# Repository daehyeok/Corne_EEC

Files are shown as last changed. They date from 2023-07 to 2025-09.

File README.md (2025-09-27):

# Corne EEC (Corne Extended Electrostatic Capacitive)

A Corne-based electrostatic capacitive (EC) keyboard featuring a number row and one additional thumb key.

> [!WARNING]
> I am not an electrical engineer. PCB design may not be optimized and could contain bugs. Use this project at your own risk.

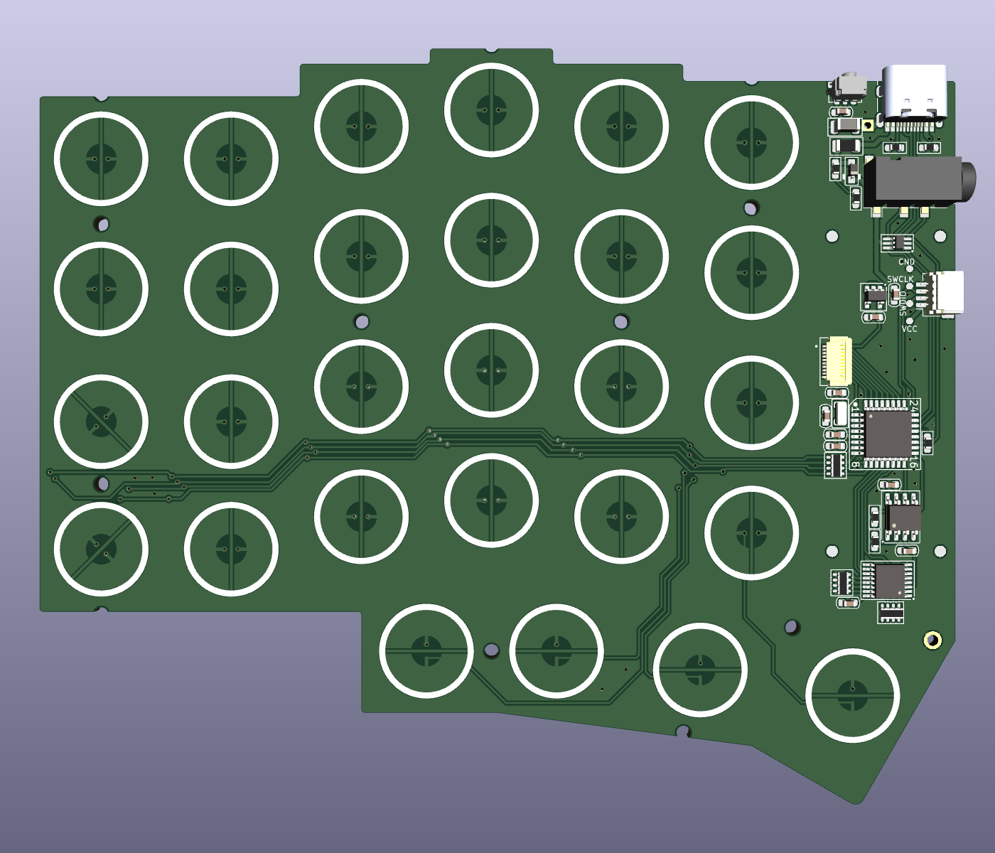
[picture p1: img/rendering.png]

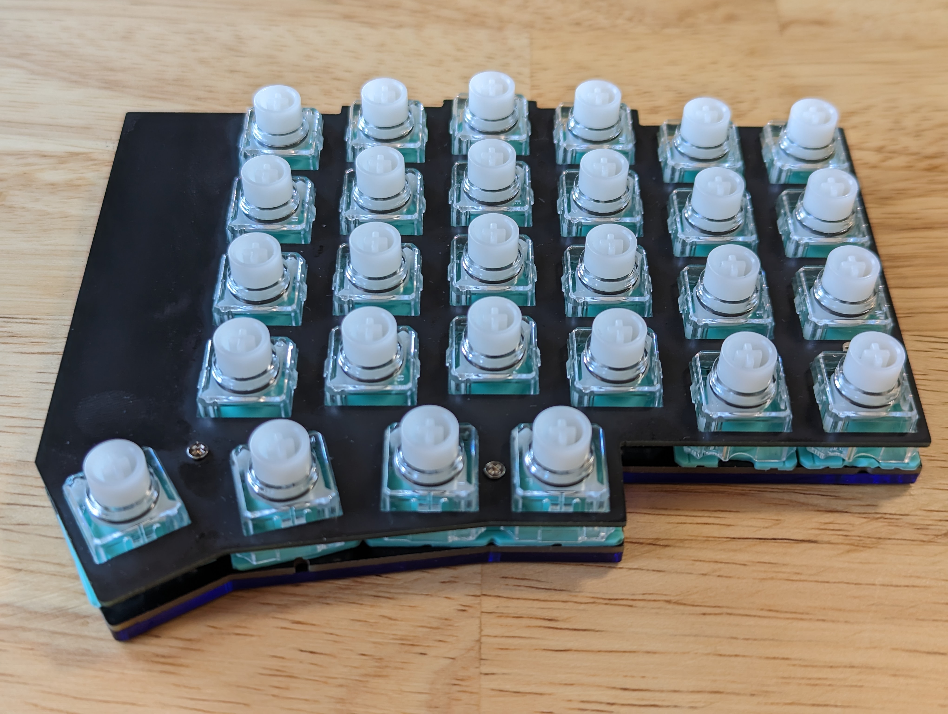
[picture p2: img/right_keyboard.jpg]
keyboard_img


## Features
* Corne-like design with a number row and 4 thumb keys, totaling 28 keys per half.
* Onboard STM32G431KBT6 MCU and USB-C with ESD protection.
* No through-hole components.
* ~~Extra PCB connectivity via a 1x06 FFC connector~~ **Rev2's FFC connector located upside down.**

## Firmware

The Rust-based firmware is hosted in a separate repository: [daehyeok/corne-eec-rs](https://github.com/daehyeok/corne-eec-rs).

## Credit

# Credit & Reference.

* [tomsmalley/custom-topre-guide](https://github.com/tomsmalley/custom-topre-guide): An invaluable resource for understanding custom Topre-style keyboards.
* [Cipulot](https://github.com/Cipulot)'s multiple PCB and firmware projects: A great source of inspiration for keyboard hardware and firmware development.
*  This project is forked from [Cipulot/CorneECRevival](https://github.com/Cipulot/CorneECRevival).

## Copyright

This project is released under the MIT License. Refer to the `LICENCE.md` file for details.

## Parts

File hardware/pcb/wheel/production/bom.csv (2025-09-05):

Designator | Footprint | Quantity | Value | LCSC Part #
H3_3, H3_2, H3, H4_3, H4_2, H4, H5_3, H5_2, H5, H6_3, H6_2, H6 | SMT-SO-M1.6-with-ring | 12 | ~
J4_3, J4_2, J4 | CONN6x1_FH34SRJ-6S-0.5SH50_HIR | 3 | HRS_FH34SRJ-06S-0.5SH(50)
R1_3, R1_2, R1, R2_3, R2_2, R2, R3_3, R3_2, R3 | 0603 | 9 | 10k
R4_3, R4_2, R4, R5_3, R5_2, R5, R6_3, R6_2, R6, R7_3, R7_2, R7, R8_3, R8_2, R8, R9_3, R9_2, R9 | 0603 | 18 | 0
SW1_3, SW1_2, SW1, SW2_3, SW2_2, SW2 | EVQWGD001 | 6 | RotaryEncoder_Switch

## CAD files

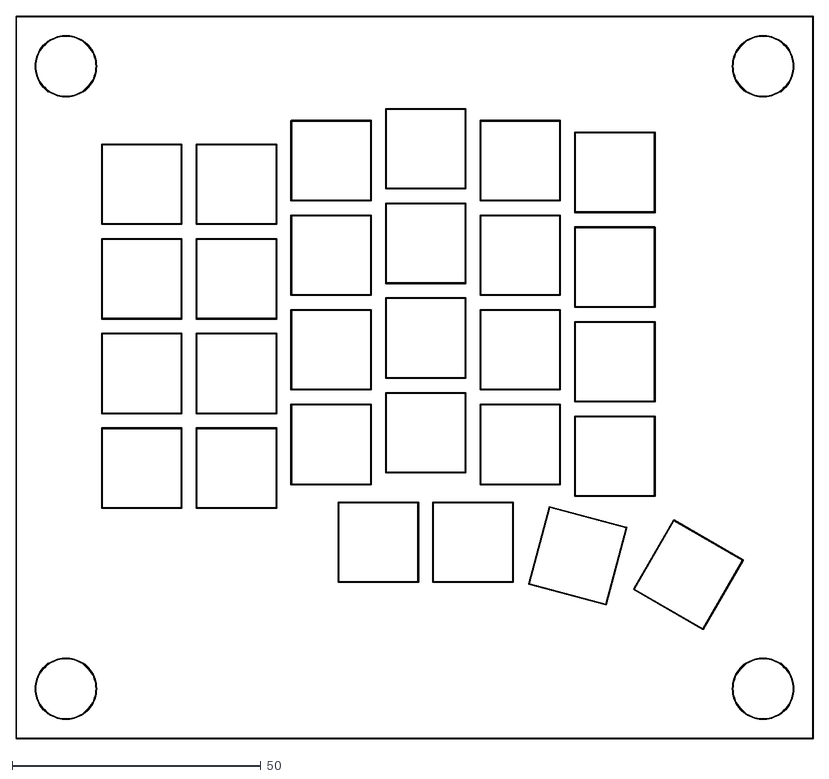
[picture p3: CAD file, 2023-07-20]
production_files/assembly_stand.dxf
160.1 x 145.1

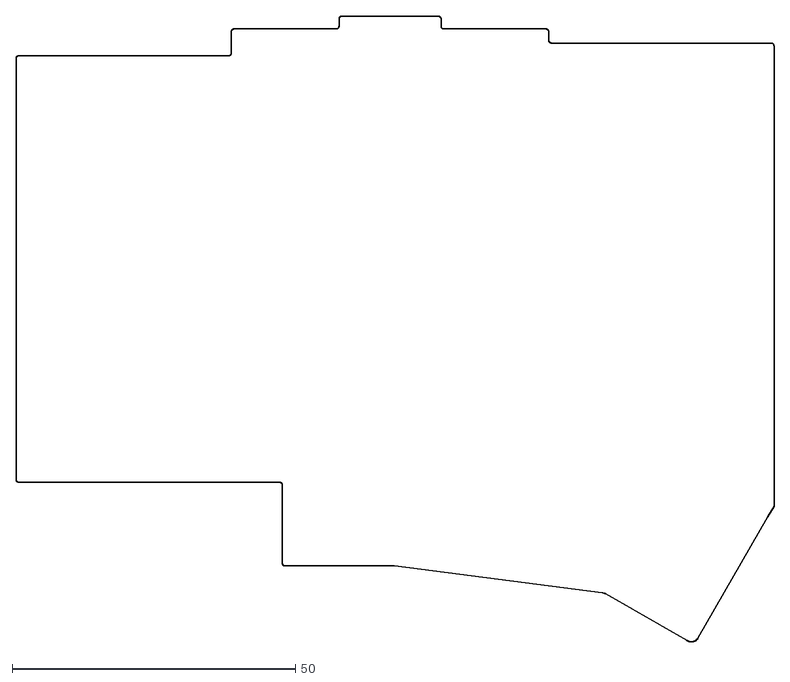
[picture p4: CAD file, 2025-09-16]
hardware/case/kicad/case-Edge_Cuts.dxf
133.8 x 110.4

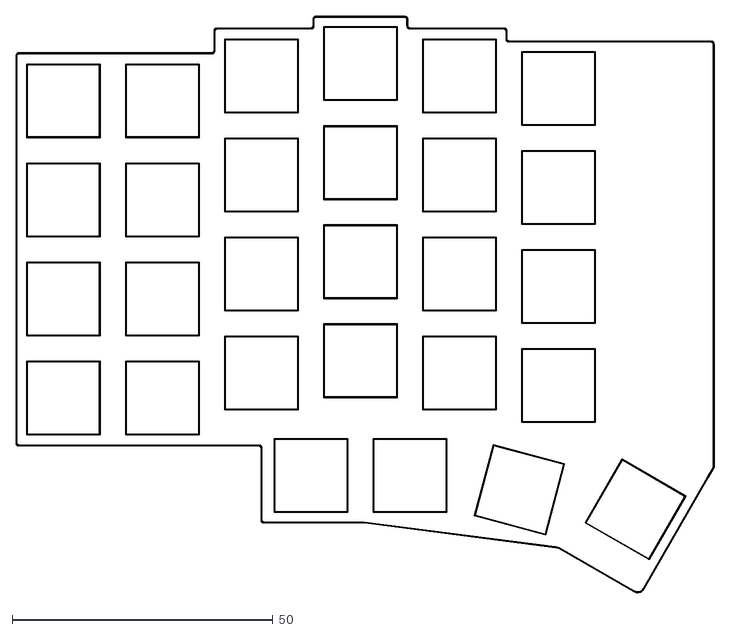
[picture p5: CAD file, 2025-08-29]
hardware/plain_plate/edge/plain_plate-Edge_Cuts.dxf
133.9 x 110.6

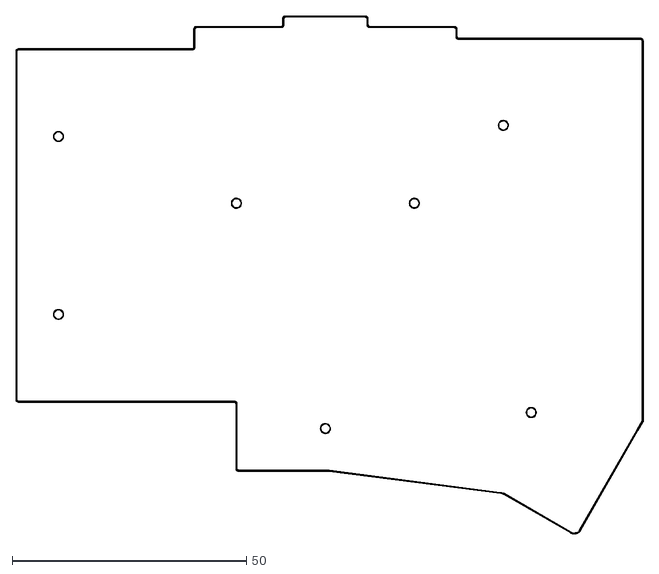
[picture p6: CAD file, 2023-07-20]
production_files/plain_plate.dxf
133.9 x 110.6

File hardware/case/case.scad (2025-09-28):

include <BOSL2/std.scad>;
$fn=64;

margin = 5;

//TODO - height
bottom_thickness = 1.5;
bottom_space = 1.5;

pcb_thickness = 1.6;
pcb_top_height = pcb_thickness;

plate_thickness = 1.2;
plate_bottom_height = pcb_top_height + 5;

standoff_height = 5;
wall_height = pcb_thickness + standoff_height + plate_thickness;

debug_jst_post= [121.773, 20.355];

usb_center_height = 3.26/2;
usb_pos = [118.05,  11.375];
//TODO fix value
usb_cutout_height = 6.5;
usb_cutout_width = 11.6;
usb_port_entry_width=11;


trrs_dia = 5.6;
trrs_radius = trrs_dia /2 ;
//x_pos == pcb_edge
trrs_pos = [124.75, -4.025, pcb_top_height +  trrs_radius];
//TODO fix value
trrs_cutout_dia = 7.5;

reset_center = 3.2/2;
reset_center_height = pcb_top_height + reset_center;
//y_pos == pcb_edge
reset_sw_pos = [108.65, 11.375, reset_center_height];
reset_dia = 2;
reset_cut_dia = 4;

//mount screw positions
m2_mount_pos = [ [38, -23.75],
                 [76, -23.75],
                 [57, -71.875],
                 ];

plate_mount_pos = [ [0, -9.5],
                    [0, -47.5],
                    [95, -7.125],
                    [100.9654, -68.4478],
                    ];

m2_screw_hole_dia = 2.05;



module pcb_outline_dxf(){
  import("./kicad/case-Edge_Cuts.dxf");
};

module pcb_cut_outline(){
  minkowski()
    {
      pcb_outline_dxf();
      circle(r=0.01);
    };
};


module case_outline(){
  minkowski()
    {
      pcb_outline_dxf();
      circle(r=margin);
    };
}

module bottom(){
  down(bottom_thickness)
    linear_extrude(bottom_thickness)
    pcb_cut_outline();
}

module wall(){
  down(bottom_thickness)
    linear_extrude(wall_height+bottom_thickness)
    difference(){
    case_outline();
    pcb_cut_outline();
  }
}

module core(){  
  union(){
    bottom();
    wall();
  }
}

module mount_cutout(){
  head_hole_dia = 4.5;
  head_hole_depth = 1;

  color("green")
    union(){
    for (pos = m2_mount_pos){
      move( concat(pos))
        down(bottom_thickness + 2)
        zrot(90)
        cylinder(d=m2_screw_hole_dia, h=10);
    }};
}

module plate_mount_cutout(){
  head_hole_dia = 4.5;
  head_hole_depth = 1;

  color("green")
    union(){
    for (pos = plate_mount_pos){
      move( concat(pos))
        down(head_hole_depth)
        zrot(-90)
        cylinder(d=head_hole_dia, h=head_hole_depth);
    }};
}


module usb_cutout_shape(){
  usb_extrude = 2;
  color("green")
    union(){
    up(pcb_thickness+0.5)
      left(usb_cutout_width/2)
      cube([usb_cutout_width, usb_extrude, 20]);
    up(usb_center_height + pcb_thickness)
      cuboid([usb_cutout_width, 20, usb_cutout_height], rounding=0.5);
  }
}
//TODO recheck
module usb_cut_out(){
  move(usb_pos)
    usb_cutout_shape();
}

//TODO
module trrs_cut_out(){
  move(trrs_pos)
    color("green")
    union(){
    cube([20, trrs_cutout_dia, 10], center=true);
  }
}

module reset_cut_out(){

  large_hole_dia =reset_cut_dia + 2;
  upside_entry_width=1.8;
  y_cut = 10;
  move(reset_sw_pos)
    color("green")
    union(){
    up(y_cut/2 - large_hole_dia/2)
      back(upside_entry_width/2)
      cube([large_hole_dia, upside_entry_width, y_cut], center = true);
    xrot(-90)
      union(){
      cylinder(d=reset_cut_dia, h = 10);
    }
  }
}

module case(){
  difference(){
    union(){
      core();
    }
    usb_cut_out();
    trrs_cut_out();
    reset_cut_out();
    mount_cutout();
    plate_mount_cutout();
  }
}

render(){
  case();
  usb_cutout_shape();
}

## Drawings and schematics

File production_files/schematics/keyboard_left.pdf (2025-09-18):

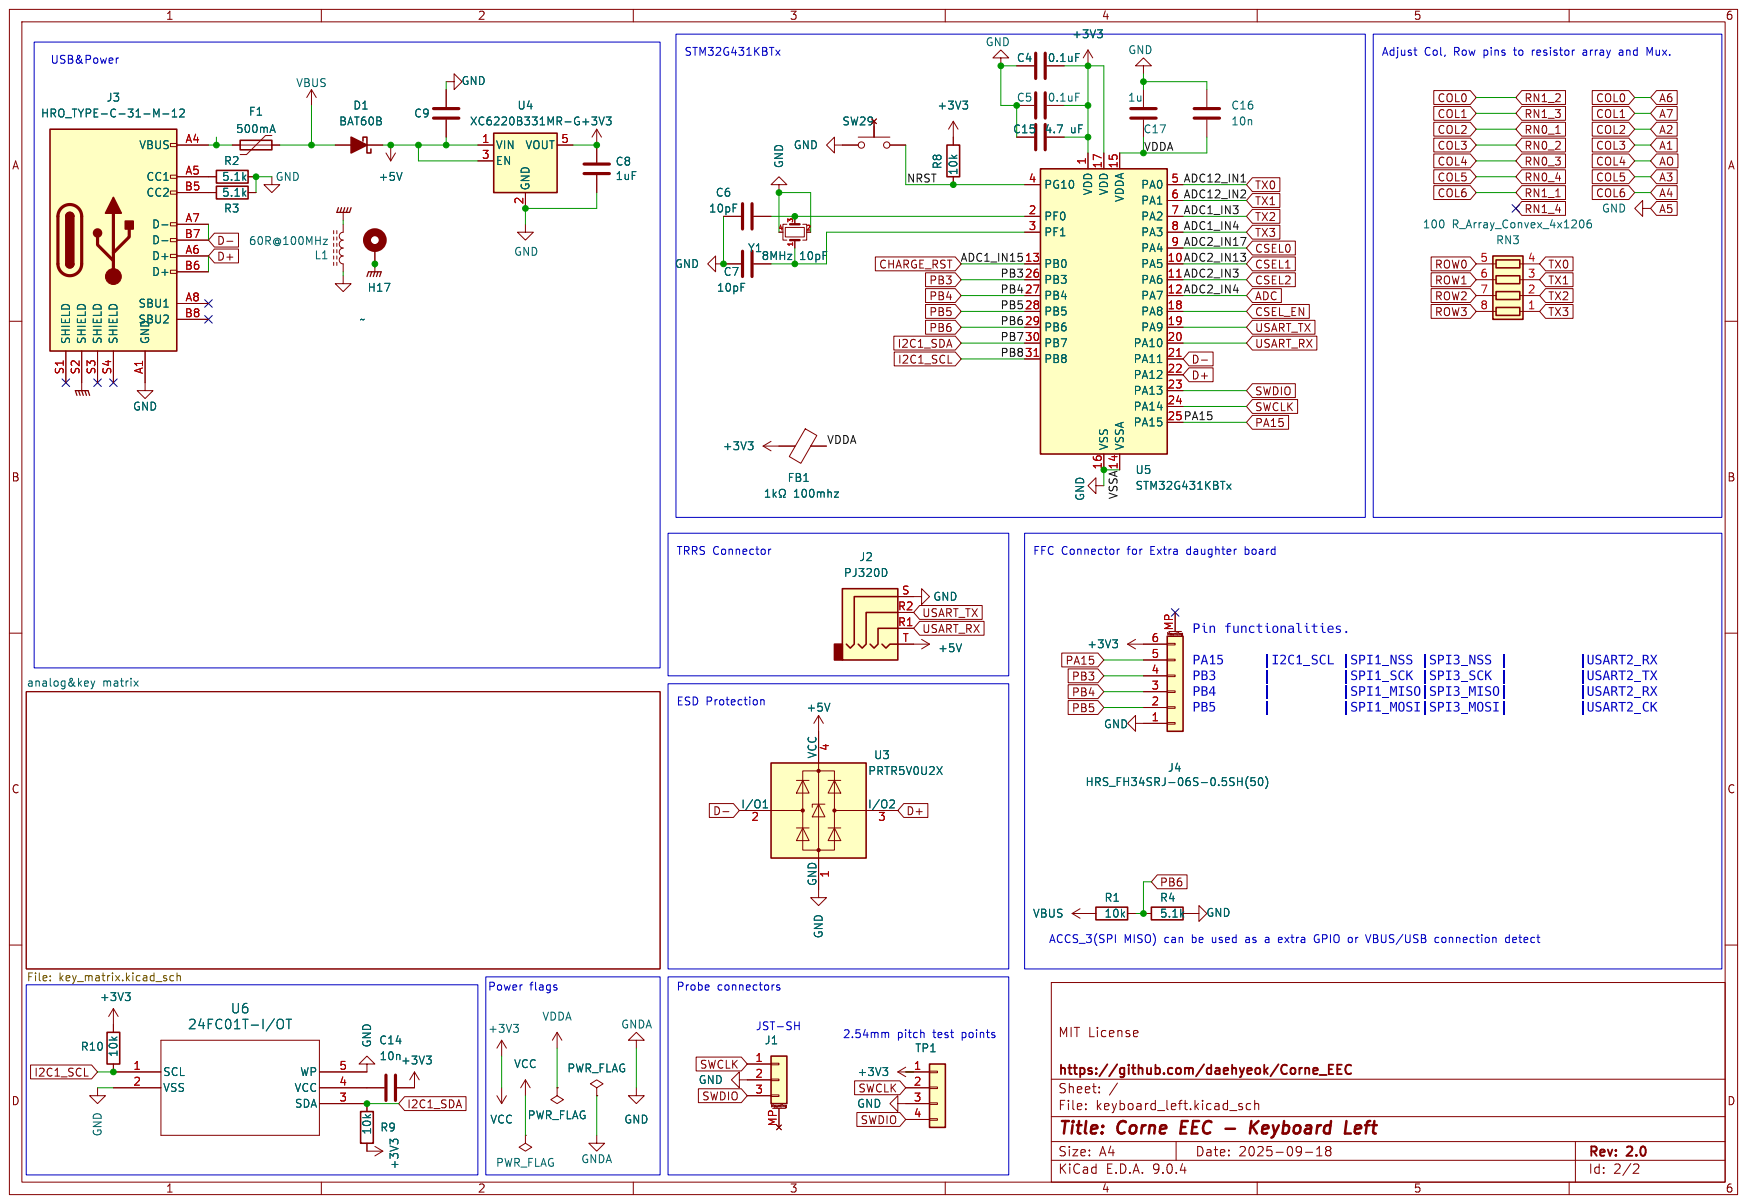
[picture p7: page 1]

https://github.com/daehyeok/Corne_EEC
Sheet: /
File: keyboard_left.kicad_sch

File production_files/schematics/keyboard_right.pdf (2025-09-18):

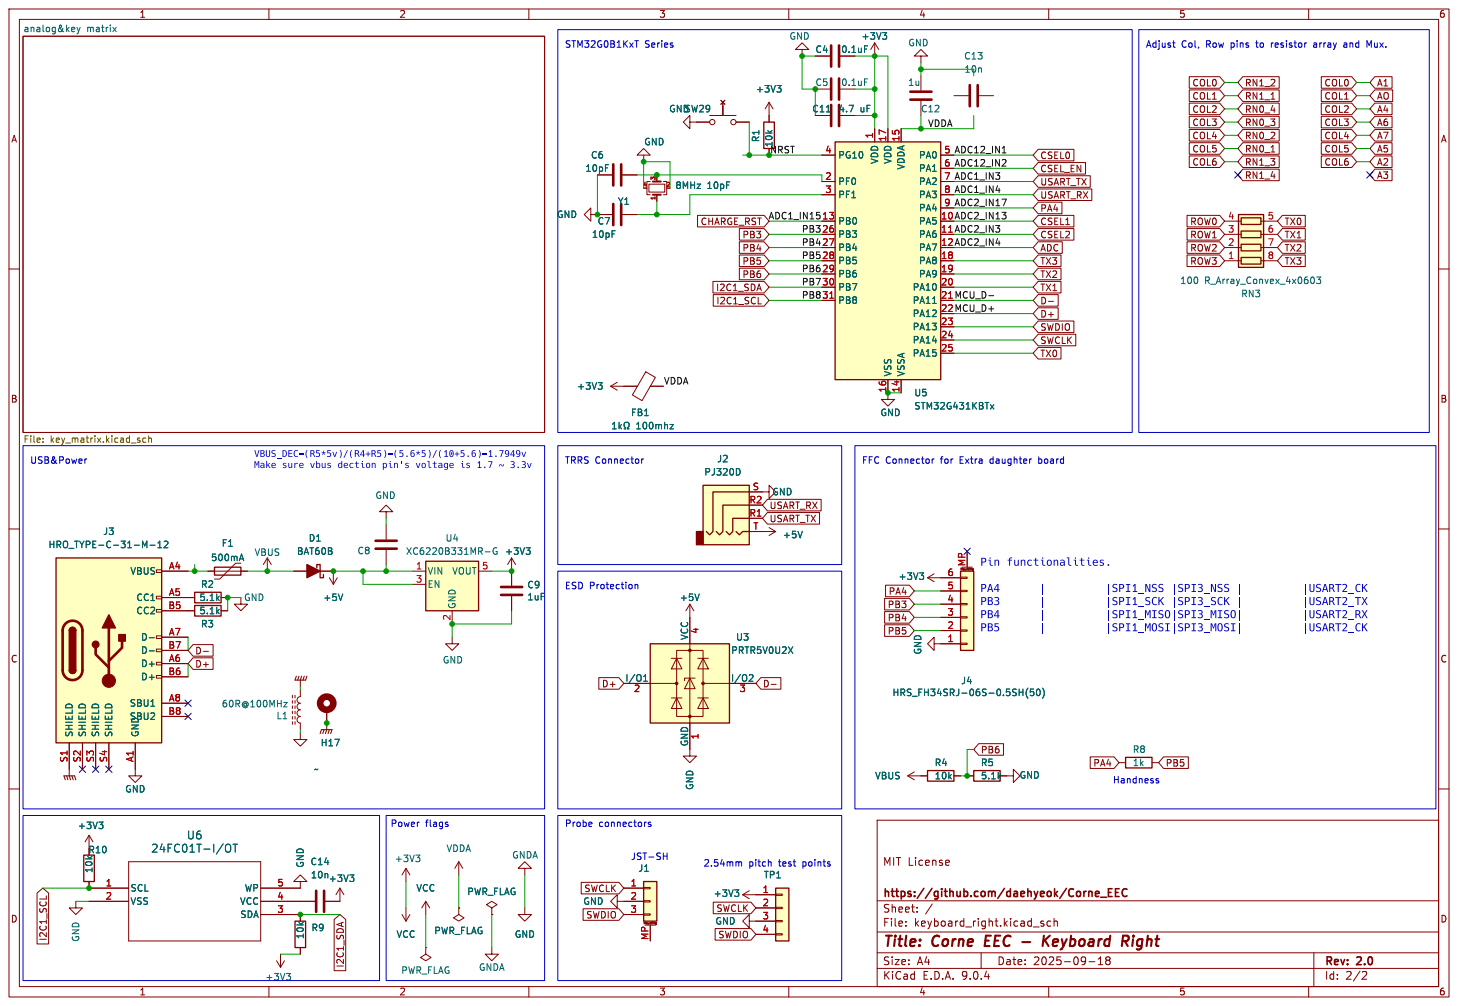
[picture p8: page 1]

1 VDD 17 VSS 16 VDDA 15 VSSA 14 PA0 5 PA1 6 PA2 7 PA3 8 PA4 9 PA5 10 PA6 11 PA7 12 PA8 18 PA9 19 PA10 20 PA11 21 PA12 22 PA13 23 PA14 24 PA15 25 U5STM32G431KBTx +3V3
1uGND

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

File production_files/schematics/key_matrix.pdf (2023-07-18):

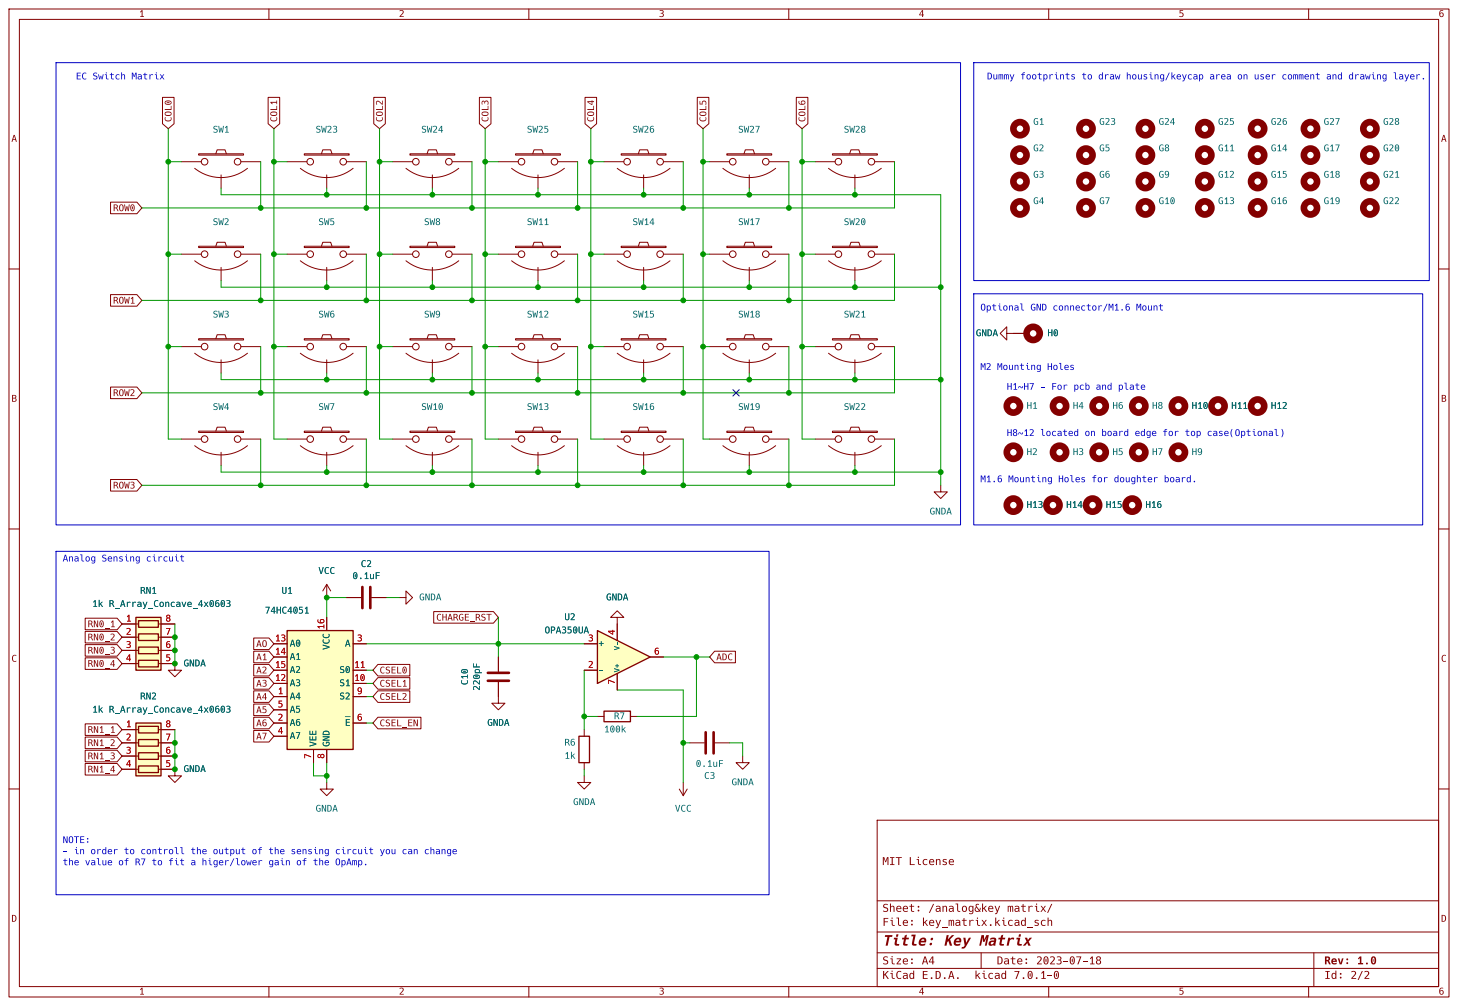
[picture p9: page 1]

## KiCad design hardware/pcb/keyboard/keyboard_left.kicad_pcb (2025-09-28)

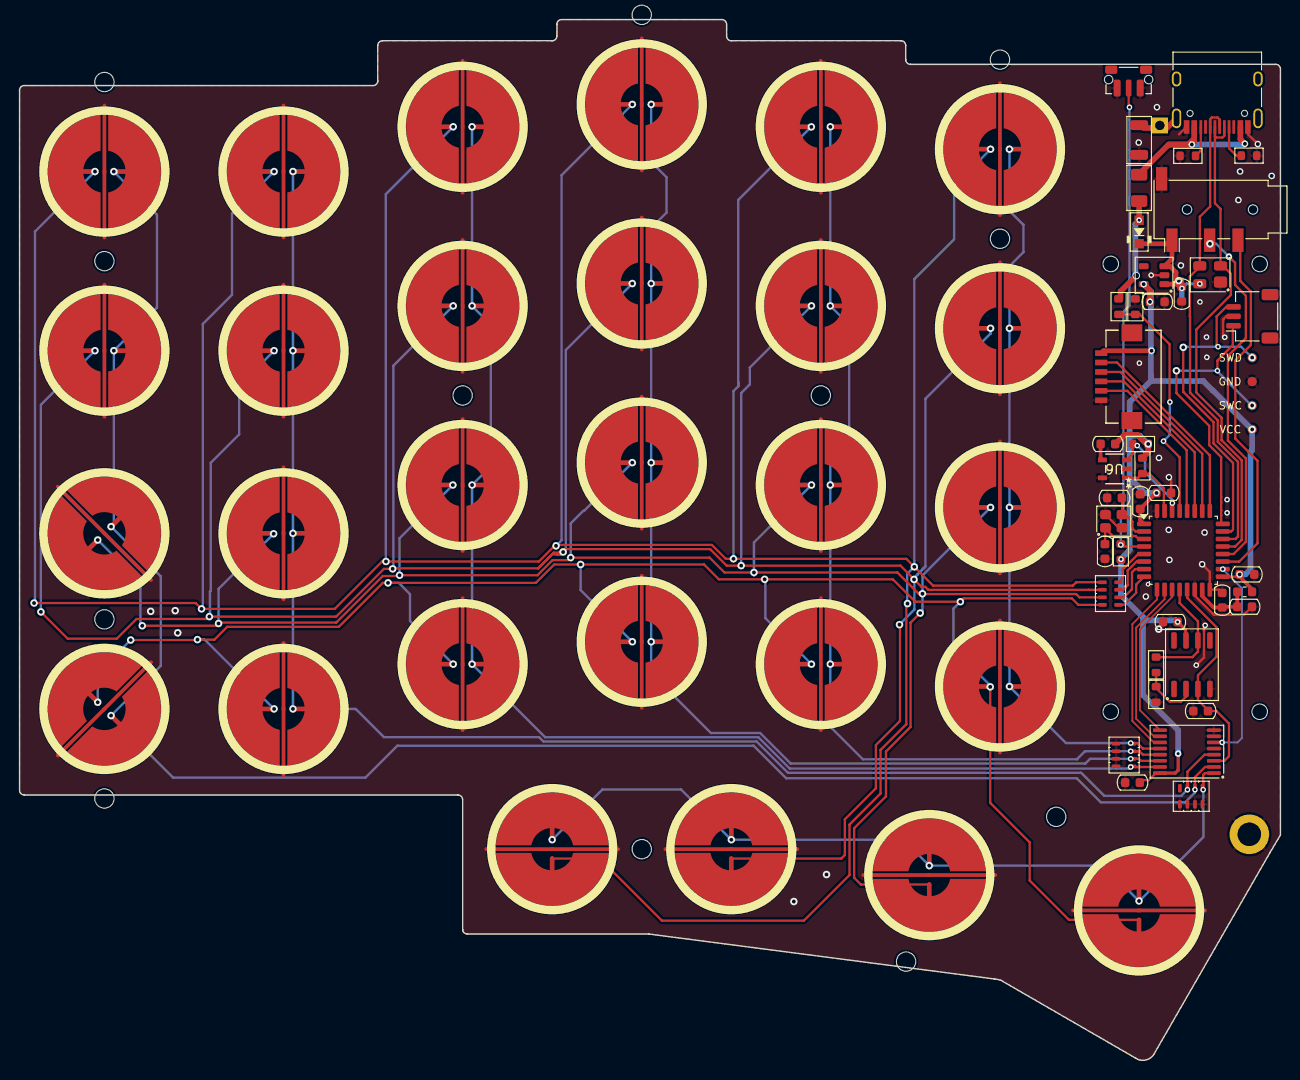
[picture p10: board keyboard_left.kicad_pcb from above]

Board: 2 copper layers, 133.8 x 110.4 mm, 116 parts (1 on the bottom side), 48 nets.

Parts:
C2, C3, C4, C5: 0.1uF; C_0603_1608Metric
C6, C7: 10pF; C_0603_1608Metric
C8, C9: 1uF; C_0603_1608Metric
C10: 220pF; C_0603_1608Metric
C14, C16: 10n; C_0603_1608Metric
C15: 4.7 uF; C_0603_1608Metric
C17: 1u; C_0603_1608Metric
D1: 1N5819; D_SOD-323_HandSoldering
F1: 500mA; Fuse_1206_3216Metric
FB1: 1kΩ 100mhz; L_0603_1608Metric
G1, G2, G3, G4, G5, G6, G7, G8, G9, G10, G11, G12, G13, G14, G15, G16, G17, G18, G19, G20, G21, G23, G24, G25, G26, G27, G28: ecs_housing_graphic
G22: ecs_housing_graphic_1.5U
H0: SMT-SO-M1.6-with-ring
H1, H2, H3, H4, H5, H6, H7, H8, H9, H10, H11, H12: MountingHole_2.05mm
H13, H14, H15, H16: SMT-SO-M1.6-screwhole_only
H17: PinHeader_1x01
J1: SM03B-SRSS-TB; JST_SH_SM03B-SRSS-TB_1x03-1MP_P1.00mm_Horizontal
J2: PJ320D; Jack_3.5mm_PJ320D_Horizontal
J3: HRO_TYPE-C-31-M-12; USB_C_Receptacle_HRO_TYPE-C-31-M-12
J4: HRS_FH34SRJ-06S-0.5SH(50); CONN6x1_FH12S-6S-1SH55
L1: 60R@100MHz; L_1206_3216Metric
R1, R8, R9, R10: 10k; R_0603_1608Metric
R2, R3, R4: 5.1k; R_0603_1608Metric
R6: 1k; R_0603_1608Metric
R7: 100k; R_0603_1608Metric
RN1, RN2: 100k R_Array_Concave_4x0603; R_Array_Concave_4x0603
RN3: 100 R_Array_Convex_4x1206; R_Array_Concave_4x0603
SW1, SW2, SW3, SW4, SW5, SW6, SW7, SW8, SW9, SW10, SW11, SW12, SW13, SW14, SW15, SW16, SW17, SW18, SW19, SW20, SW21, SW22, SW23, SW24, SW25, SW26, SW27, SW28: ecs_pad_no_ring
SW29: PTS845; SW_Push_1P1T-MP_NO_Horizontal_Alps_SKRTLAE010
TP1: PinHeader_1x04_P2.54mm_test_pad
U1: 74HC4051; TSSOP-16_4.4x5mm_P0.65mm
U2: OPA350UA; SO-8_3.9x4.9mm_P1.27mm
U3: PRTR5V0U2X; SOT-143
U4: XC6220B331MR-G; SOT-23-5
U5: STM32G431KBTx; LQFP-32_7x7mm_P0.8mm
U6: 24FC01T-I/OT; SOT-23-5_2P9X1P6_MCH
Y1: 8MHz 10pF; Crystal_SMD_2520-4Pin_2.5x2.0mm

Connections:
+3V3: C2.2, C3.2, C4.1, C5.1, C8.1, C14.1, C15.1, FB1.2, J4.6, R8.2, R9.2, R10.1, TP1.1, U1.16 (VCC), U2.7 (V+), U4.5 (VOUT), U5.1 (VDD), U5.17 (VDD)
+5V: C9.1, D1.1 (K), J2.T, U3.4 (VCC), U4.1 (VIN), U4.3 (EN)
/NRST: R8.1, SW29.2, U5.4 (PG10)
A1: RN1.2 (R2.1), SW11.1, SW12.1, SW13.1, SW25.1, U1.14 (A1)
A2: RN1.1 (R1.1), SW8.1, SW9.1, SW10.1, SW24.1, U1.15 (A2)
A3: RN1.4 (R4.1), SW17.1, SW18.1, SW19.1, SW27.1, U1.12 (A3)
A4: RN2.1 (R1.1), SW20.1, SW21.1, SW22.1, SW28.1, U1.1 (A4)
A5: C2.1, C3.1, C4.2, C5.2, C6.1, C7.1, C8.2, C9.2, C10.2, C15.2, C16.2, C17.2, H0.1, J1.2, J2.S, J3.A1 (GND), J3.A12 (GND), J3.B1 (GND), J3.B12 (GND), J4.1, L1.1, R2.2, R3.2, R4.1, R6.2, RN1.5 (R4.2), RN1.6 (R3.2), RN1.7 (R2.2), RN1.8 (R1.2), RN2.5 (R4.2), RN2.6 (R3.2), RN2.7 (R2.2), RN2.8 (R1.2), SW1.3 (SG), SW2.3 (SG), SW3.3 (SG), SW4.3 (SG), SW5.3 (SG), SW6.3 (SG), SW7.3 (SG), SW8.3 (SG), SW9.3 (SG), SW10.3 (SG), SW11.3 (SG), SW12.3 (SG), SW13.3 (SG), SW14.3 (SG), SW15.3 (SG), SW16.3 (SG), SW17.3 (SG), SW18.3 (SG), SW19.3 (SG), SW20.3 (SG), SW21.3 (SG), SW22.3 (SG), SW23.3 (SG), SW24.3 (SG), SW25.3 (SG), SW26.3 (SG), SW27.3 (SG), SW28.3 (SG), SW29.1, TP1.3, U1.5 (A5), U1.7 (VEE), U1.8 (GND), U2.4 (V-), U3.1 (GND), U4.2 (GND), U5.14 (VSSA), U5.16 (VSS), U5.32 (VSS), U6.2 (VSS), U6.5 (WP), Y1.2, Y1.4
A6: RN2.2 (R2.1), SW1.1, SW2.1, SW3.1, SW4.1, U1.2 (A6)
A7: RN2.3 (R3.1), SW5.1, SW6.1, SW7.1, SW23.1, U1.4 (A7)
ADC: R7.1, U2.6, U5.12 (PA7)
AO: RN1.3 (R3.1), SW14.1, SW15.1, SW16.1, SW26.1, U1.13 (A0)
CHARGE_RST: C10.1, U1.3 (A), U2.3 (+), U5.13 (PB0)
CSEL0: U1.11 (S0), U5.9 (PA4)
CSEL1: U1.10 (S1), U5.10 (PA5)
CSEL2: U1.9 (S2), U5.11 (PA6)
CSEL_EN: U1.6 (~E), U5.18 (PA8)
D+: J3.A6 (D+), J3.B6 (D+), U3.3 (I/O2), U5.22 (PA12)
D-: J3.A7 (D-), J3.B7 (D-), U3.2 (I/O1), U5.21 (PA11)
GNDPWR: H17.1, J3.S2 (SHIELD), L1.2
I2C1_SCL: R10.2, U5.31 (PB8), U6.1 (SCL)
I2C1_SDA: R9.1, U5.30 (PB7), U6.3 (SDA)
unnamed: F1.2, J3.A4 (VBUS), J3.A9 (VBUS), J3.B4 (VBUS), J3.B9 (VBUS)
unnamed: J3.A5 (CC1), R2.1
unnamed: J3.B5 (CC2), R3.1
unnamed: R6.1, R7.2, U2.2 (-)
unnamed: C6.2, U5.2 (PF0), Y1.3
unnamed: C7.2, U5.3 (PF1), Y1.1
unnamed: C14.2, U6.4 (VCC)
PA15: J4.5, U5.25 (PA15)
PB3: J4.4, U5.26 (PB3)
PB4: J4.3, U5.27 (PB4)
PB5: J4.2, U5.28 (PB5)
PB6: R1.1, R4.2, U5.29 (PB6)
ROW0: RN3.5 (R4.2), SW1.2, SW23.2, SW24.2, SW25.2, SW26.2, SW27.2, SW28.2
ROW1: RN3.6 (R3.2), SW2.2, SW5.2, SW8.2, SW11.2, SW14.2, SW17.2, SW20.2
ROW2: RN3.7 (R2.2), SW3.2, SW6.2, SW9.2, SW12.2, SW15.2, SW18.2, SW21.2
ROW3: RN3.8 (R1.2), SW4.2, SW7.2, SW10.2, SW13.2, SW16.2, SW19.2, SW22.2
SWCLK: J1.1, TP1.2, U5.24 (PA14)
SWDIO: J1.3, TP1.4, U5.23 (PA13)
TX0: RN3.4 (R4.1), U5.5 (PA0)
TX1: RN3.3 (R3.1), U5.6 (PA1)
TX2: RN3.2 (R2.1), U5.7 (PA2)
TX3: RN3.1 (R1.1), U5.8 (PA3)
USART_RX: J2.R1, U5.20 (PA10)
USART_TX: J2.R2, U5.19 (PA9)
VBUS: D1.2 (A), F1.1, R1.2
VDDA: C16.1, C17.1, FB1.1, U5.15 (VDDA)

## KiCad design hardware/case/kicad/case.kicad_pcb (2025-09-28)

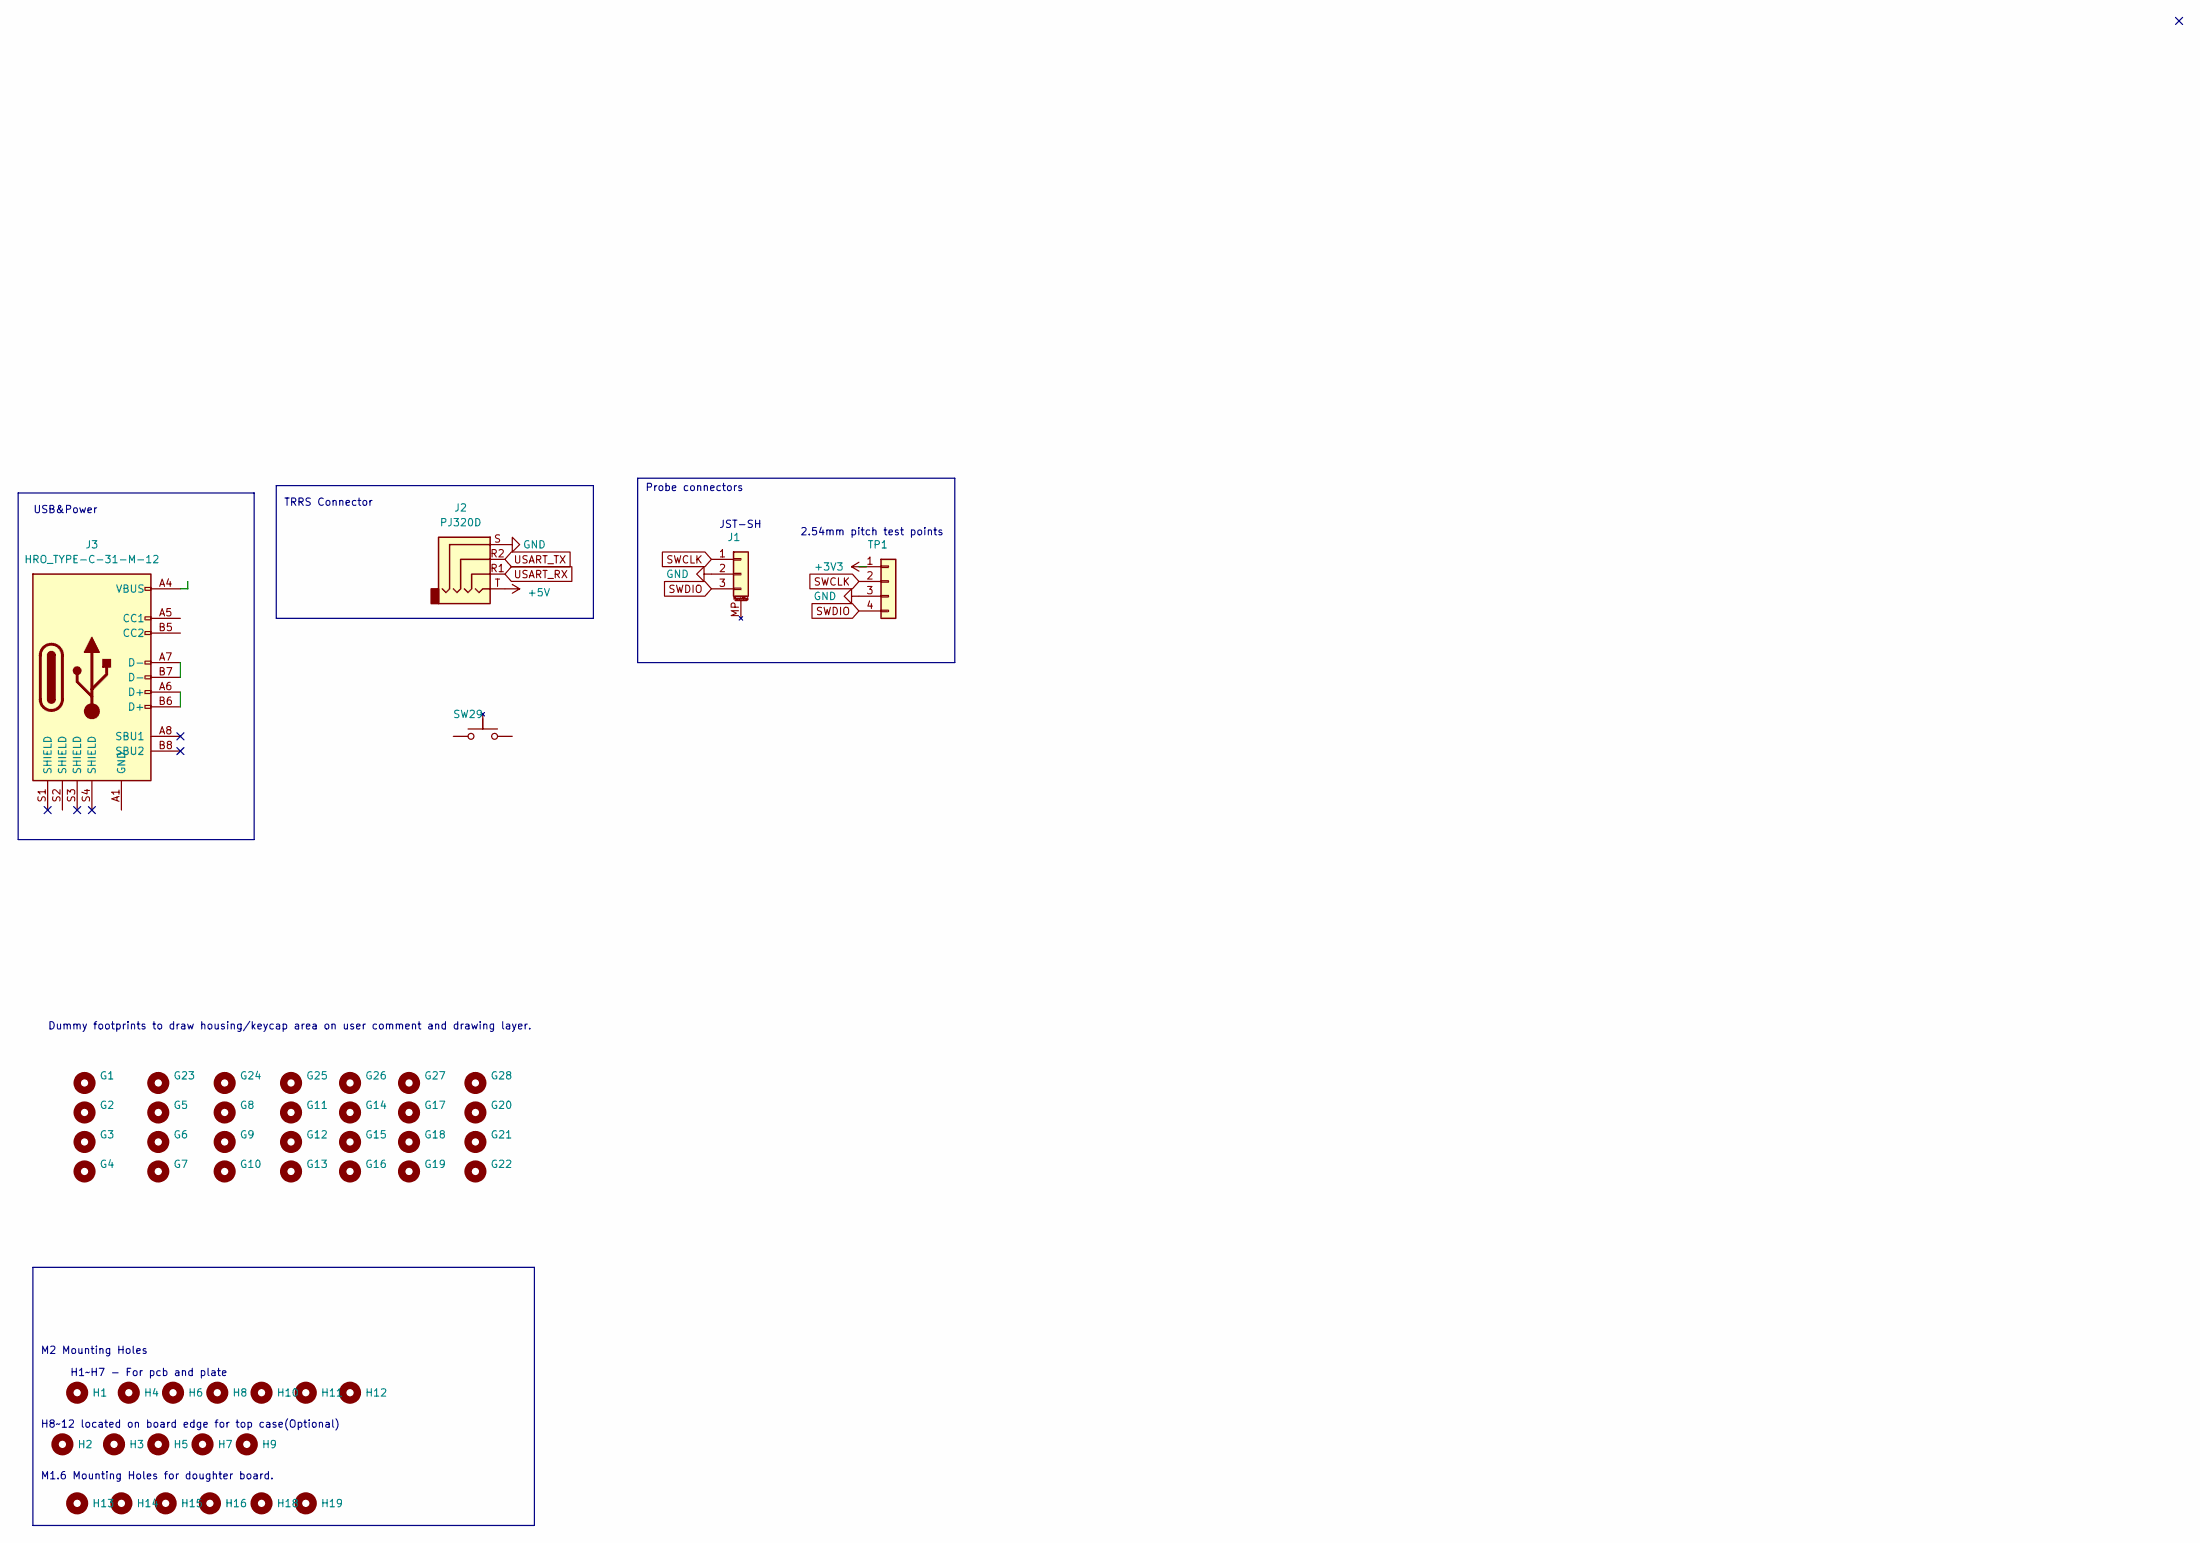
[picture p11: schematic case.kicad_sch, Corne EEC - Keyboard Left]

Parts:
G1, G2, G3, G4, G5, G6, G7, G8, G9, G10, G11, G12, G13, G14, G15, G16, G17, G18, G19, G20, G21, G23, G24, G25, G26, G27, G28: ecs_housing_graphic
G22: ecs_housing_graphic_1.5U
H1, H2, H3, H4, H5, H6, H7, H8, H9, H10, H11, H12: MountingHole_2.05mm
H13, H14, H15, H16, H18, H19: SMT-SO-M1.6-screwhole_only
J1: SM03B-SRSS-TB; JST_SH_SM03B-SRSS-TB_1x03-1MP_P1.00mm_Horizontal
J2: PJ320D; Jack_3.5mm_PJ320D_Horizontal
J3: HRO_TYPE-C-31-M-12; USB_C_Receptacle_HRO_TYPE-C-31-M-12
SW29: PTS845; SW_Push_1P1T-MP_NO_Horizontal_Alps_SKRTLAE010
TP1: PinHeader_1x04_P2.54mm_test_pad

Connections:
+3V3: TP1.1
+5V: J2.T
GND: J1.2, J2.S, TP1.3
unnamed: J3.A6 (D+), J3.B6 (D+)
unnamed: J3.A7 (D-), J3.B7 (D-)
unnamed: J3.A1 (GND), J3.A12 (GND), J3.B1 (GND), J3.B12 (GND)
unnamed: J3.A4 (VBUS), J3.A9 (VBUS), J3.B4 (VBUS), J3.B9 (VBUS)
SWCLK: J1.1, TP1.2
SWDIO: J1.3, TP1.4
USART_RX: J2.R1
USART_TX: J2.R2

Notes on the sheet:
Probe connectors
TRRS Connector
USB&Power
JST-SH
M2 Mounting Holes
M1.6 Mounting Holes for doughter board.
Dummy footprints to draw housing/keycap area on user comment and drawing layer.
H1~H7 - For pcb and plate
2.54mm pitch test points
H8~12 located on board edge for top case(Optional)

Board: 2 copper layers, 52 parts (1 on the bottom side), 7 nets, no tracks yet.

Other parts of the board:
H12#2: MountingHole_2.05mm

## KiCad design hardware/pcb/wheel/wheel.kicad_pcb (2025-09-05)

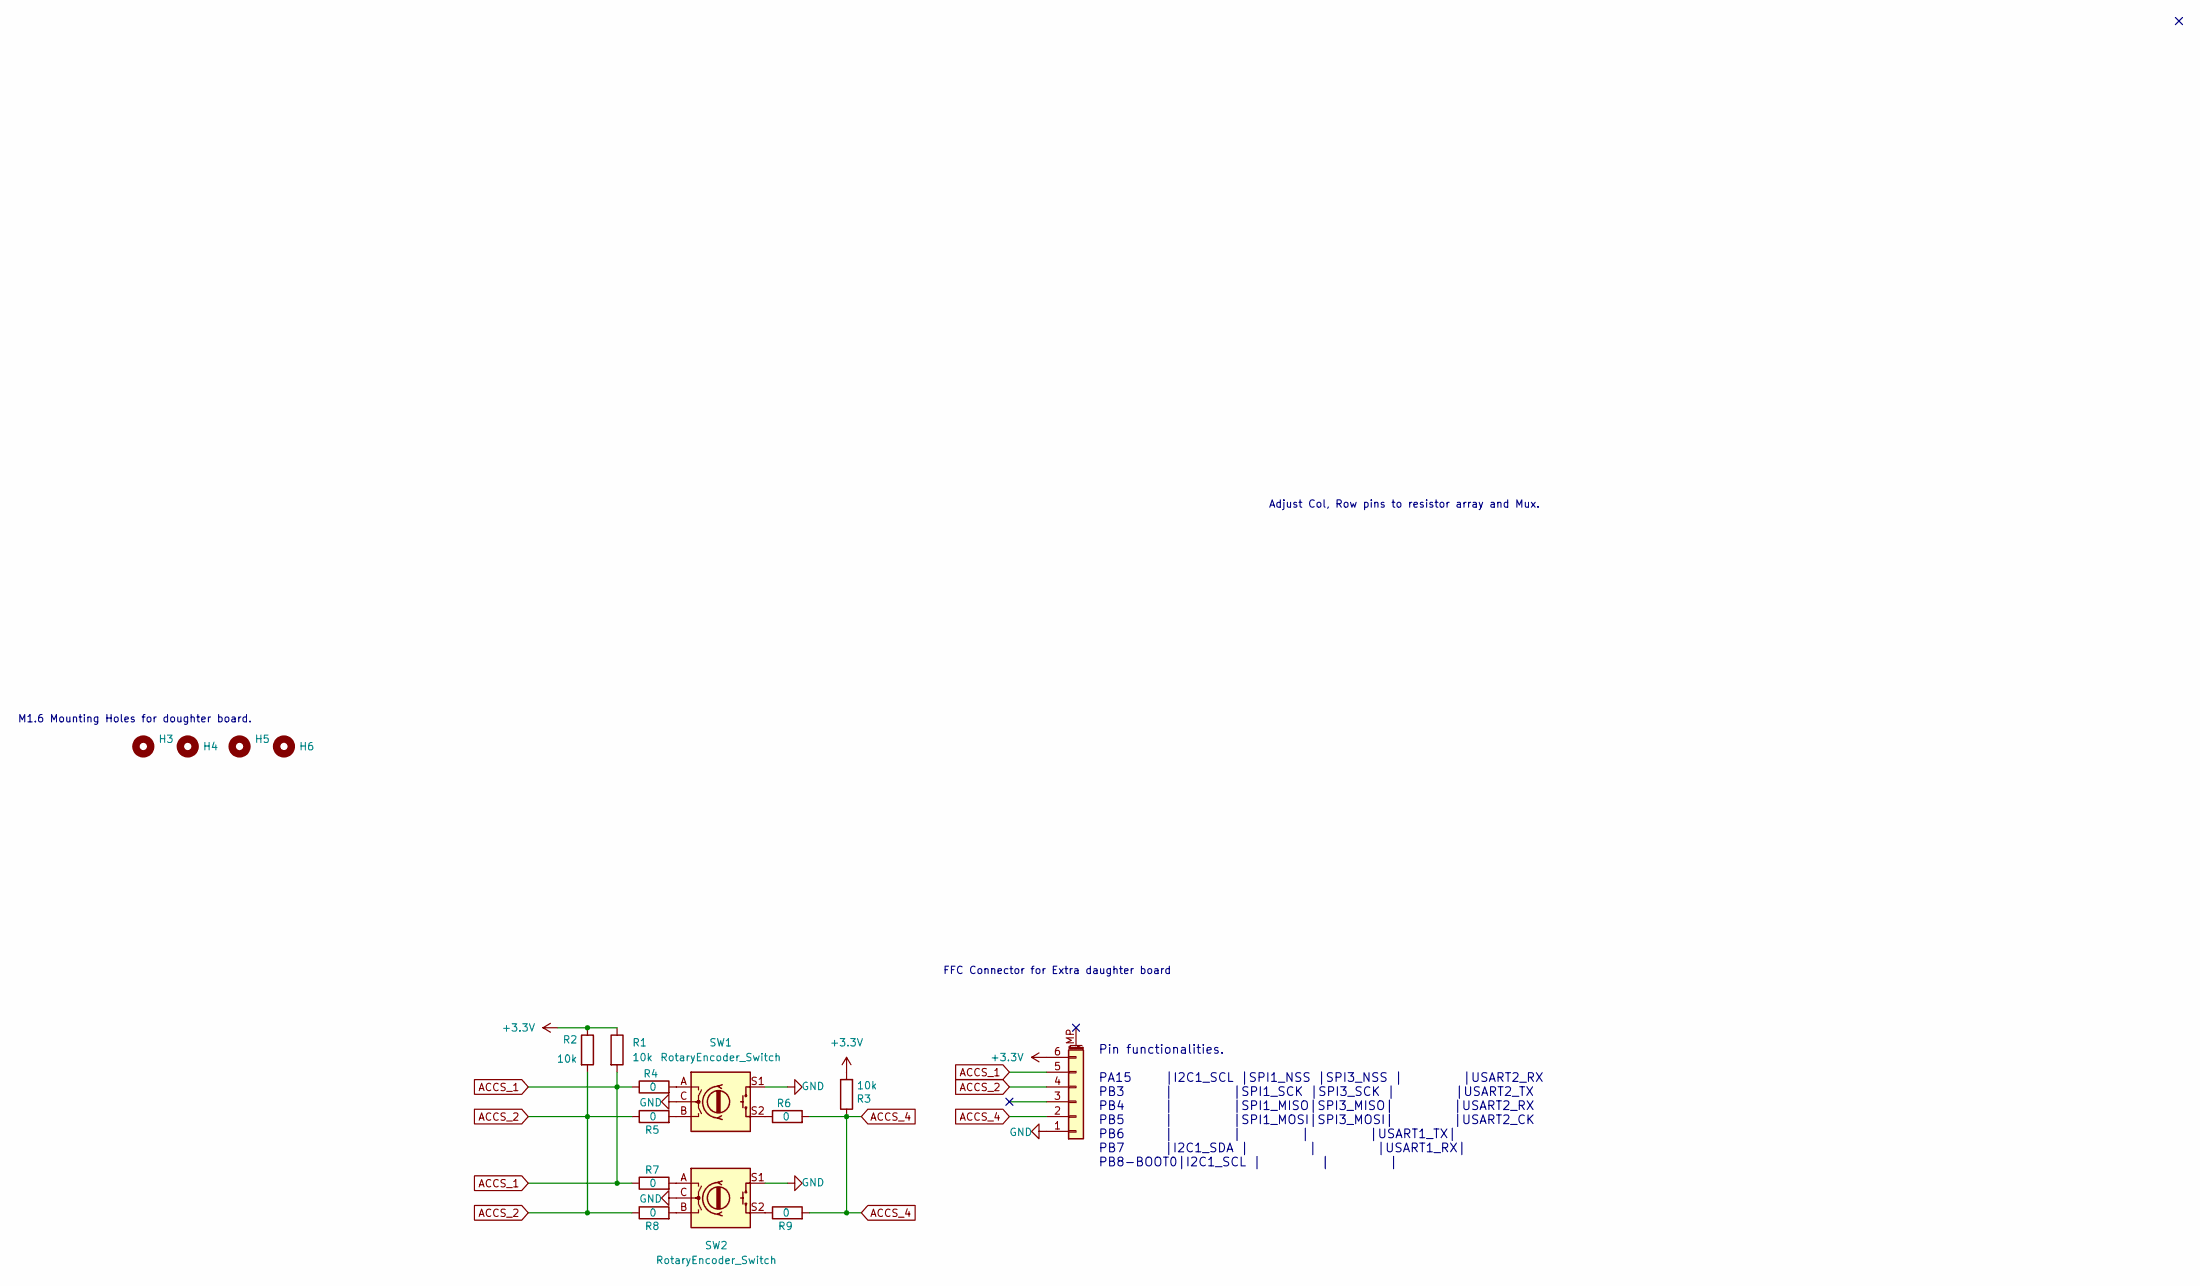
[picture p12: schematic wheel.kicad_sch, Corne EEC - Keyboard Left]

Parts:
H3, H4, H5, H6: SMT-SO-M1.6-screwhole_only
J4: HRS_FH34SRJ-06S-0.5SH(50); CONN6x1_FH34SRJ-6S-0.5SH50_HIR
R1, R2, R3: 10k; R_0603_1608Metric_Pad1.05x0.95mm_HandSolder
R4, R5, R6, R7, R8, R9: 0; R_0603_1608Metric_Pad1.05x0.95mm_HandSolder
SW1, SW2: RotaryEncoder_Switch; EVQWGD001

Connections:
+3.3V: J4.6, R1.1, R2.1, R3.2
ACCS_1: J4.5, R1.2, R4.1, R7.1
ACCS_2: J4.4, R2.2, R5.1, R8.1
ACCS_4: J4.2, R3.1, R6.2, R9.2
GND: J4.1, SW1.C, SW1.S1, SW2.C, SW2.S1
unnamed: R4.2, SW1.A
unnamed: R5.2, SW1.B
unnamed: R6.1, SW1.S2
unnamed: R7.2, SW2.A
unnamed: R8.2, SW2.B
unnamed: R9.1, SW2.S2

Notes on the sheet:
FFC Connector for Extra daughter board
Adjust Col, Row pins to resistor array and Mux.
M1.6 Mounting Holes for doughter board.
Pin functionalities. PA15 |I2C1_SCL |SPI1_NSS |SPI3_NSS | |USART2_RX PB3 | |SPI1_SCK |SPI3_SCK | |USART2_TX PB4 | |SPI1_MISO|SPI3_MISO| |USART2_RX PB5 | |SPI1_MOSI|SPI3_MOSI| |USART2_CK PB6 | | | |USART1_TX| PB7 |I2C1_SDA | | |USART1_RX| PB8-BOOT0|I2C1_SCL | | |

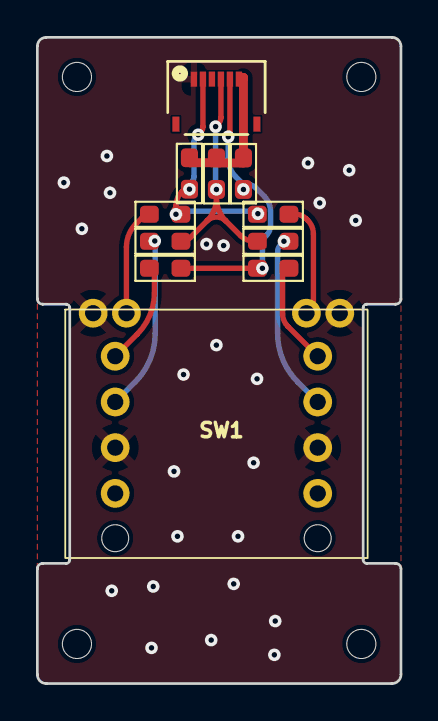
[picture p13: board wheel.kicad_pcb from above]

Board: 2 copper layers, 20.2 x 35.9 mm, 16 parts (1 on the bottom side), 11 nets.

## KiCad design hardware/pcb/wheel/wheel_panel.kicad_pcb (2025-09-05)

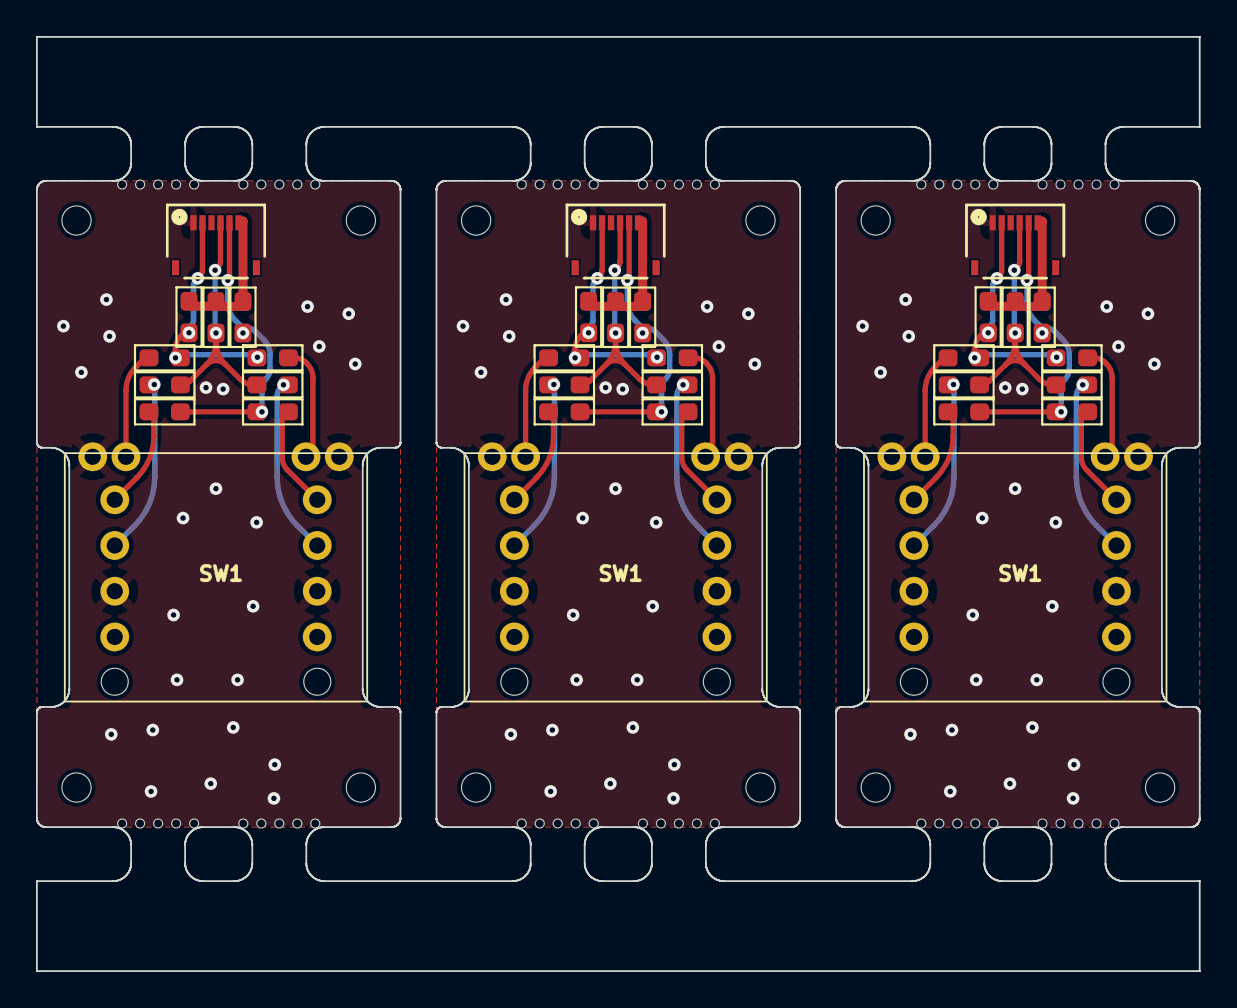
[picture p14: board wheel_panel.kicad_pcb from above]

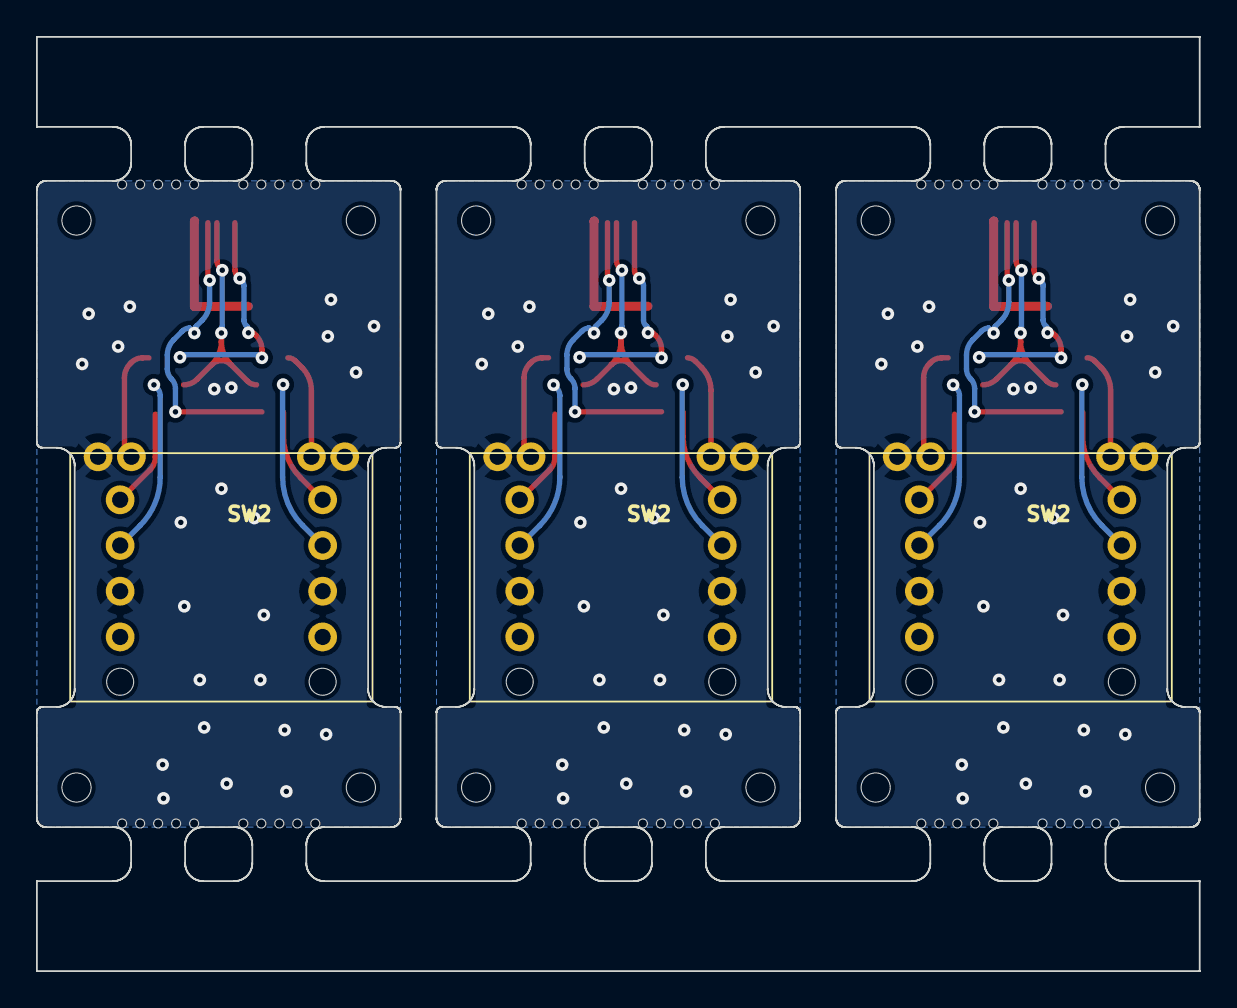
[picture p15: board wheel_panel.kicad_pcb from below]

Board: 2 copper layers, 64.6 x 51.9 mm, 108 parts (3 on the bottom side), 33 nets.

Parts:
H3, H3#2, H3#3, H4, H4#2, H4#3, H5, H5#2, H5#3, H6, H6#2, H6#3: SMT-SO-M1.6-with-ring
J4, J4#2, J4#3: HRS_FH34SRJ-06S-0.5SH(50); CONN6x1_FH34SRJ-6S-0.5SH50_HIR
KiKit_MB_1_1, KiKit_MB_1_2, KiKit_MB_1_3, KiKit_MB_1_4, KiKit_MB_1_5, KiKit_MB_2_1, KiKit_MB_2_2, KiKit_MB_2_3, KiKit_MB_2_4, KiKit_MB_2_5, KiKit_MB_3_1, KiKit_MB_3_2, KiKit_MB_3_3, KiKit_MB_3_4, KiKit_MB_3_5, KiKit_MB_4_1, KiKit_MB_4_2, KiKit_MB_4_3, KiKit_MB_4_4, KiKit_MB_4_5, KiKit_MB_5_1, KiKit_MB_5_2, KiKit_MB_5_3, KiKit_MB_5_4, KiKit_MB_5_5, KiKit_MB_6_1, KiKit_MB_6_2, KiKit_MB_6_3, KiKit_MB_6_4, KiKit_MB_6_5, KiKit_MB_7_1, KiKit_MB_7_2, KiKit_MB_7_3, KiKit_MB_7_4, KiKit_MB_7_5, KiKit_MB_8_1, KiKit_MB_8_2, KiKit_MB_8_3, KiKit_MB_8_4, KiKit_MB_8_5, KiKit_MB_9_1, KiKit_MB_9_2, KiKit_MB_9_3, KiKit_MB_9_4, KiKit_MB_9_5, KiKit_MB_10_1, KiKit_MB_10_2, KiKit_MB_10_3, KiKit_MB_10_4, KiKit_MB_10_5, KiKit_MB_11_1, KiKit_MB_11_2, KiKit_MB_11_3, KiKit_MB_11_4, KiKit_MB_11_5, KiKit_MB_12_1, KiKit_MB_12_2, KiKit_MB_12_3, KiKit_MB_12_4, KiKit_MB_12_5: NPTH
R1, R1#2, R1#3, R2, R2#2, R2#3, R3, R3#2, R3#3: 10k; R_0603_1608Metric_Pad1.05x0.95mm_HandSolder
R4, R4#2, R4#3, R5, R5#2, R5#3, R6, R6#2, R6#3, R7, R7#2, R7#3, R8, R8#2, R8#3, R9, R9#2, R9#3: 0; R_0603_1608Metric_Pad1.05x0.95mm_HandSolder
SW1, SW1#2, SW1#3, SW2, SW2#2, SW2#3: RotaryEncoder_Switch; EVQWGD001

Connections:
Board_0-+3.3V: J4#3.6, R1#2.1, R2#3.1, R3.2
Board_0-ACCS_1: J4#3.5, R1#2.2, R4#2.1, R7#3.1
Board_0-ACCS_2: J4#3.4, R2#3.2, R5#2.1, R8#3.1
Board_0-ACCS_4: J4#3.2, R3.1, R6#3.2, R9#3.2
Board_0-GND: J4#3.1, SW1#3.C, SW1#3.S1, SW2#3.C, SW2#3.S1
Board_0-Net-(R4-Pad2): R4#2.2, SW1#3.A
Board_0-Net-(R5-Pad2): R5#2.2, SW1#3.B
Board_0-Net-(R6-Pad1): R6#3.1, SW1#3.S2
Board_0-Net-(R7-Pad2): R7#3.2, SW2#3.A
Board_0-Net-(R8-Pad2): R8#3.2, SW2#3.B
Board_0-Net-(R9-Pad1): R9#3.1, SW2#3.S2
Board_1-+3.3V: J4.6, R1#3.1, R2.1, R3#3.2
Board_1-ACCS_1: J4.5, R1#3.2, R4#3.1, R7#2.1
Board_1-ACCS_2: J4.4, R2.2, R5#3.1, R8#2.1
Board_1-ACCS_4: J4.2, R3#3.1, R6.2, R9.2
Board_1-GND: J4.1, SW1#2.C, SW1#2.S1, SW2#2.C, SW2#2.S1
Board_1-Net-(R4-Pad2): R4#3.2, SW1#2.A
Board_1-Net-(R5-Pad2): R5#3.2, SW1#2.B
Board_1-Net-(R6-Pad1): R6.1, SW1#2.S2
Board_1-Net-(R7-Pad2): R7#2.2, SW2#2.A
Board_1-Net-(R8-Pad2): R8#2.2, SW2#2.B
Board_1-Net-(R9-Pad1): R9.1, SW2#2.S2
Board_2-+3.3V: J4#2.6, R1.1, R2#2.1, R3#2.2
Board_2-ACCS_1: J4#2.5, R1.2, R4.1, R7.1
Board_2-ACCS_2: J4#2.4, R2#2.2, R5.1, R8.1
Board_2-ACCS_4: J4#2.2, R3#2.1, R6#2.2, R9#2.2
Board_2-GND: J4#2.1, SW1.C, SW1.S1, SW2.C, SW2.S1
Board_2-Net-(R4-Pad2): R4.2, SW1.A
Board_2-Net-(R5-Pad2): R5.2, SW1.B
Board_2-Net-(R6-Pad1): R6#2.1, SW1.S2
Board_2-Net-(R7-Pad2): R7.2, SW2.A
Board_2-Net-(R8-Pad2): R8.2, SW2.B
Board_2-Net-(R9-Pad1): R9#2.1, SW2.S2

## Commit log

2022-01-30 Upload of firmwares
    BEWARE:
    - `crkbd_ecwl_default.hex` is compiled with gonnoc's own fork and branch, based on the old QMK 6.1
    - `crkbd_ecrevival_default.hex` is compiled with the current stable QMK, it has some flaws, described below, but the general functionality is preserved.
    As of now the Original ECWL has a wider range of sensibility. The EC revival one doesn't have that fine control. I'm working on a patch/rework of the custom matrix implementation to solve this.
    For proper testing and fine tuning I STRONGLY advice to self compile the branch that gonnoc has (qmk_firmware, dev/ecwl).
2022-01-30 Update of current release
2022-01-31 Add of standard mounting compatible PCBs
    [OG_mounting_left.kicad_pcb, OG_mounting_plate.kicad_pcb, OG_mounting_right.kicad_pcb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]
2022-01-31 Update of rev commit to include extra screw mount
    [OG_mounting_left.kicad_pcb, OG_mounting_plate.kicad_pcb, OG_mounting_right.kicad_pcb]
2022-02-03 PCB Update and STEP upload
    [corneec.kicad_sch, plate.step]
2022-02-04 Upload STEP files
    [OG_mounting_plate.step, OG_mounting_plate_Topre.kicad_pcb, OG_mounting_plate_Topre.step]
2022-02-22 Updated EC pad footprint
    [OG_mounting_left.kicad_pcb, OG_mounting_right.kicad_pcb, corneec.kicad_pcb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]
2022-02-28 Fix footprint
    Fix of outdated footprint that introduced a "no track" rule where it was not supposed to be implemented.
    [OG_mounting_left.kicad_pcb, corneec.kicad_pcb, corneec_right.kicad_pcb]
2022-03-08 Folder structure update
    [BOM-corneec.csv, OG_mounting_left.kicad_pcb, OG_mounting_plate.kicad_pcb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]
2022-03-16 Update config.h
    Previously defined values changed after seeing that the deviation in the values from the left side was caused by the specific pro micro board I was using.
2022-03-22 Addition of ECWL compatible Topre plate
    [plate_Topre.kicad_pcb]
2022-03-22 Update production file format
    [OG_mounting_left.kicad_pcb, OG_mounting_plate.kicad_pcb, OG_mounting_plate_Topre.kicad_pcb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]
2022-04-18 Moved 3d models from PCB to Assets
    [OG_mounting_plate.step, OG_mounting_plate_Topre.step, plate.step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]
2022-04-18 Update of PCB and models
    [OG_mounting_left.kicad_pcb, OG_mounting_plate_Topre.kicad_pcb, OG_mounting_right.kicad_pcb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]
2022-04-19 Update files for JLC production (minimal assembly)
    [Assembly-BOM-CorneECRevival.csv, General-BOM-CorneECRevival.csv, OG_mounting_left.kicad_pcb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]
2022-04-19 Reupload gerber
2022-04-27 Consolidation folder in prep for Rev2
    [Assembly-BOM-CorneECRevival.csv, General-BOM-CorneECRevival.csv, OG_mounting_left.kicad_pcb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]
2022-04-27 Moved 3d models to dedicated RevX folder
    [OG_mounting_plate.step, OG_mounting_plate_Topre.step, plate.step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]
2022-05-12 Fix pad numbering
    [OG_mounting_left.kicad_pcb, OG_mounting_right.kicad_pcb, corneec_right.kicad_pcb]
2022-08-09 FIX Production files
    Fix to the production files that caused one of the 2 EC pads to be merged with the ground plane.
    [OG_mounting_left.kicad_pcb, OG_mounting_right.kicad_pcb, corneec.kicad_pcb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]
2023-06-23 remove unsued files
    [Assembly-BOM-CorneECRevival.csv, General-BOM-CorneECRevival.csv, OG_mounting_left.kicad_pcb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]
2023-07-18 Init STM32G0 PCB
    [BOM-keyboard_left.csv, BOM-keyboard_right.csv, analog.kicad_sch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]
2023-07-18 Fix capacitor, resistor values
    [BOM-keyboard_left.csv, BOM-keyboard_right.csv, key_matrix.kicad_sch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]
2023-07-20 Add plate and assembly stand laser cut
    [BOM-keyboard_left.csv, BOM-keyboard_right.csv, assembly_stand.dxf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]
2023-07-23 Add 3d files and rendering image
    [keyboard_left.kicad_pcb, keyboard_right.kicad_pcb]
2023-07-24 roate FFC Connector
    [BOM-keyboard_left.csv, keyboard_left.kicad_pcb, keyboard_left.kicad_sch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]
2023-08-07 Left init
    [keyboard_left.kicad_pcb, keyboard_left.kicad_sch]
2023-08-12 Right init
    [key_matrix.kicad_sch, keyboard_left.kicad_pcb, keyboard_left.kicad_sch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]
2023-08-13 usb hib init
    [key_matrix.kicad_sch, keyboard_left.kicad_pcb, keyboard_left.kicad_sch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]
2025-08-22 rev2 pre production
    [BOM-keyboard_left.csv, BOM-keyboard_right.csv, keyboard_left.kicad_pcb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]
2025-08-25 init memory
    [key_matrix.kicad_sch, keyboard_left.kicad_pcb, keyboard_left.kicad_sch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]
2025-08-29 add pull up register for I2C.
    [keyboard_left.kicad_pcb, keyboard_left.kicad_sch, keyboard_right.kicad_pcb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]
2025-08-31 fix acc connection.
    [keyboard_left.kicad_pcb, keyboard_left.kicad_sch, keyboard_right.kicad_pcb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]
2025-08-31 update schema.
    [key_matrix.kicad_sch, keyboard_left.kicad_pcb, keyboard_left.kicad_sch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]
2025-09-08 Change crystal
    [keyboard_left.kicad_sch, keyboard_right.kicad_sch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]
2025-09-16 init 3d case.
    [case-Edge_Cuts.dxf, case.kicad_pcb, case.kicad_sch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]
2025-09-18 Generate production files.
    [bom.csv, designators.csv, keyboard_left.kicad_pcb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]
2025-09-27 stencil temp
    [bom.csv, designators.csv, key_matrix.kicad_sch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]
2025-09-28 Rev 2.1
    [case.kicad_pcb, case.scad, key_matrix.kicad_sch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]

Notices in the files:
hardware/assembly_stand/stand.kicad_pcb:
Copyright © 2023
